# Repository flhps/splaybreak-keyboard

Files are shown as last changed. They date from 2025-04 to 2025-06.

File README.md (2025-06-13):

# SplayBreak

_A simple but versatile 36-key split ergonomic wireless keyboard._

---

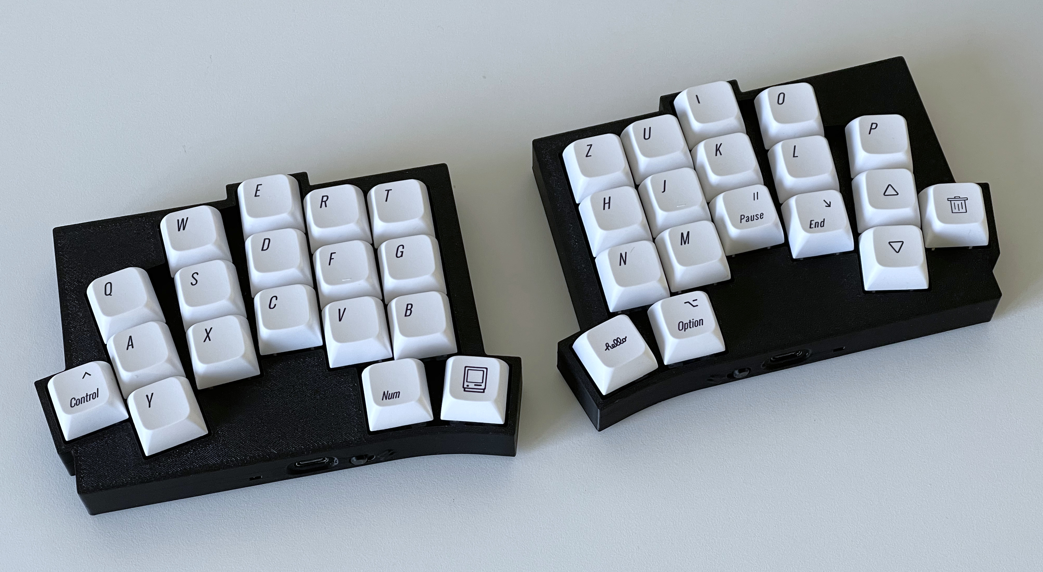
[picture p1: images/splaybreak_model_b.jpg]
Model B

_Model B with MX switches and XDA keycaps_
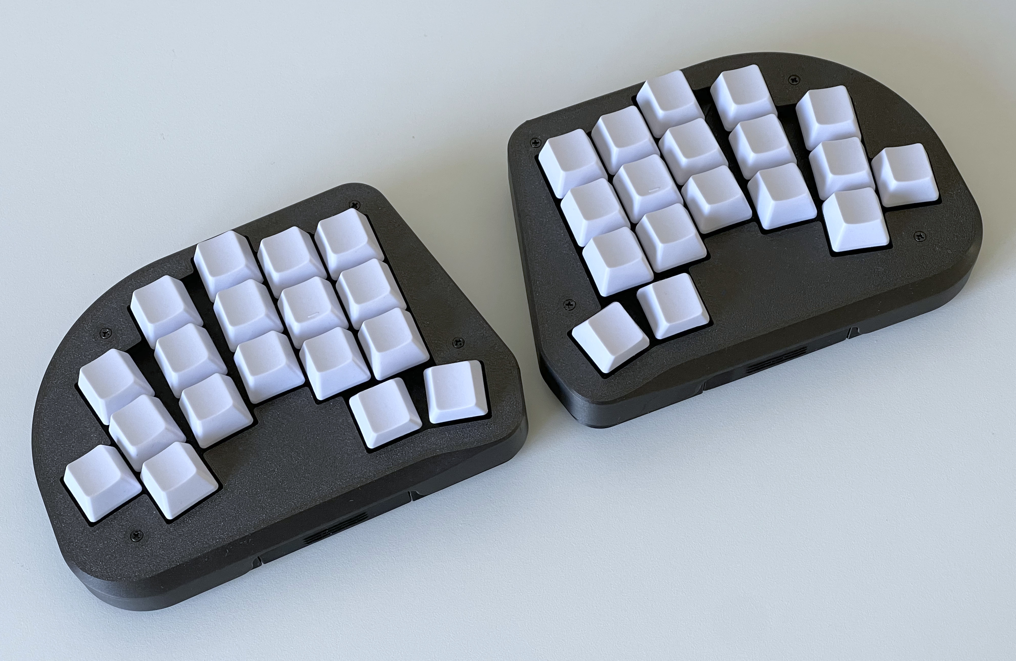
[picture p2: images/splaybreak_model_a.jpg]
Model A

_Model A with MX switches and OEM keycaps_

This is a split keyboard, that is heavily inspired by my recent personal dive into the world of open mechanical split keyboards. At the time of writing, I have used these two models on an almost daily basis for over 6 months.

## Features

There are two models that use the same PCB and mostly the same build parts:

| Model | Hot Swap MX | Hot Swap Choc V1 | Gasket Mount | Battery | Magnetic Access Hatch | Nice Buttons and Port |
| --- | --- | --- | --- | --- | --- | --- |
| [A](/build-guide-a.md) | ✅ | ⚠ | ✅ | 2000mAh | ✅ | |
| [B](/build-guide-b.md) | ✅ | ⚠ | | 500mAh  | | ✅ |

More information can be found in the individual build guides:

- [SplayBreak Model A](/build-guide-a.md)
- [SplayBreak Model B](/build-guide-b.md)

> [!WARNING]
> While the PCB accepts hot swap sockets for Choc V1 switches, the case dimensions are not tested with them.

## Design Rationale

A big focus was to keep this keyboard somewhat simple and cheap. That is why it uses the popular Pro Micro controllers and that limits the number of keys per side to 18 because we want to avoid having to solder diodes. The keyboards are wireless with massive batteries for easier daily use at home and on the go. Since the whole keyboard layout is in the firmware, these can also be used with devices such as phones or tablets. While screens can be cool, this design has none because they cost money and reduce battery life.

For flexibility (and cost reduction), the PCB is reversible. It means you need to order less and any PCB you have left can replace one that you accidentally destroyed. Also, the PCB has support for MX switches and Choc v1 switches. That would enable the use of this PCB for a super thin travel option.

There are only two thumb keys, because they would increase the design's footprint by a lot if they were to be positioned comfortably. The current inner thumb key is the resting position, meaning a third one would have to be even more toward the inside. However, I wanted to create a somewhat compact key arrangement and case.
Instead, the extra thumb key is moved to the pinky. This emulates the extra outer keys like tab or enter on a conventional keyboard an is intended to make it easier for people who frequently switch between conventional and split keyboards. It also makes switching from a conventional keyboard to this one easier.

This project features two different keyboard models, which only differ in assembly instructions and the provided case files, which are FDM-printable. I was never a big fan of the very gritty designs featuring lots of open electronics, so I designed some fully enclosed cases.

For repairability, model A has everything socketed, making error search and replacements easier. It is also built to improve sound through a gasket mount. Model B foregoes some of that and becomes more compact and arguably more stylish. There, the controller is soldered directly to the PCB.

## Firmware and Layout

Both models can use the same firmware. I have prepared a template that already contain a usable layout:

[zmk-config-splaybreak-template](https://github.com/flhps/zmk-config-splaybreak-template)

## Open Ideas and TODOs

- clean up the PCB and make it more aesthetic (transparent case?)
- create another model as a thin travel option with choc v1
- more in-depth build guides

## Development

Build ergogen in the `ergogen` directory:

```sh
ergogen --clean .
```

## Attributions

Big inspirations were:

- [TOTEM](https://github.com/GEIGEIGEIST/TOTEM)
- [Ferris Sweep](https://github.com/davidphilipbarr/Sweep)

The design uses ergogen footprints from [@ceoloide's ergogen PCB footprints](https://github.com/ceoloide/ergogen-footprints).
The reversible hotswap footprint for both MX and Choc is extracted from the [Lily58 Pro's](https://github.com/kata0510/Lily58) kicad file.

The [ergogen guide](https://flatfootfox.com/ergogen-introduction/) from FlatFootFox was very helpful.

And of course, this project would probably not exist without the excellent tool that is [ergogen](https://github.com/ergogen/ergogen).

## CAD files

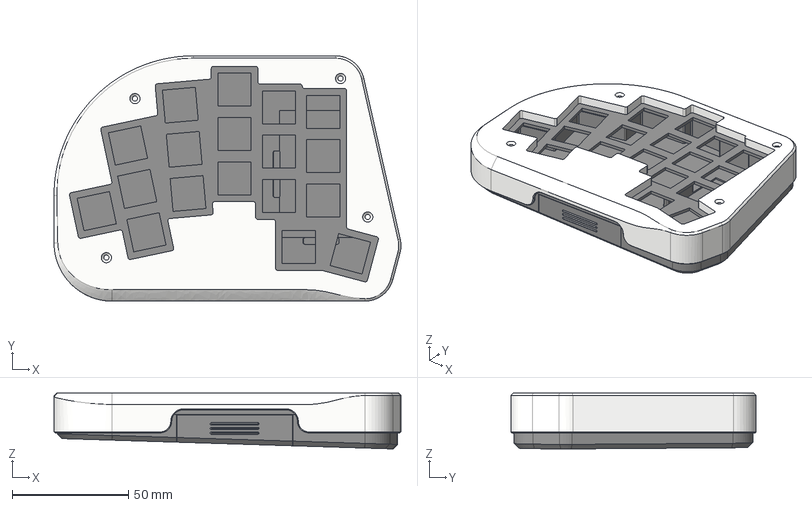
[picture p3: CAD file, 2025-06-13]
cases/SplayBreak Case Model A.step
149.1 x 105.4 x 24.0 mm

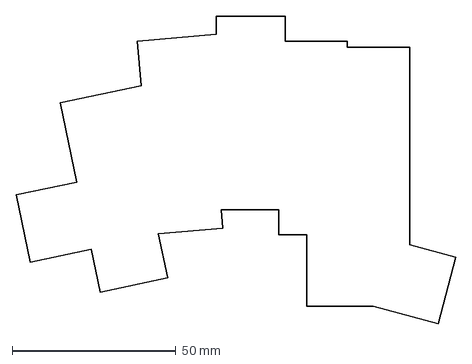
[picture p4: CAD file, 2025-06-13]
ergogen/output/outlines/combined_raw.dxf
134.3 x 94.0 mm

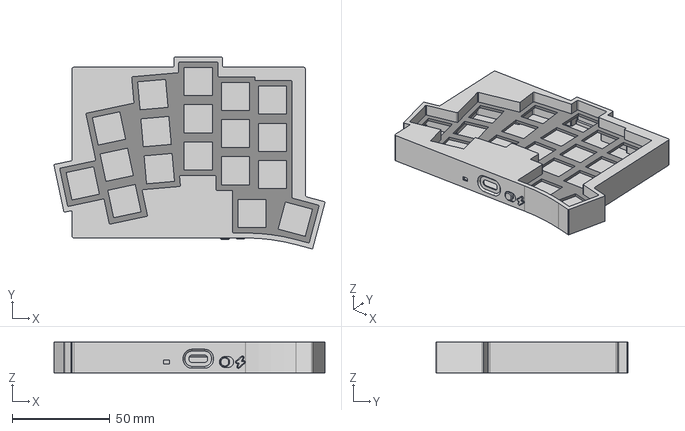
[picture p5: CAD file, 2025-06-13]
cases/SplayBreak Case Model B.step
139.0 x 98.3 x 15.7 mm

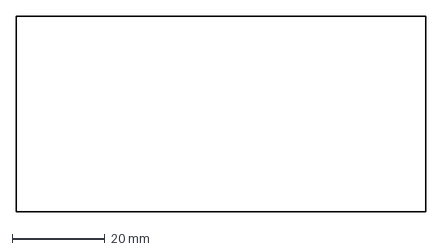
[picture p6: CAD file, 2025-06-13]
ergogen/output/outlines/io_rect.dxf
88.4 x 42.1 mm

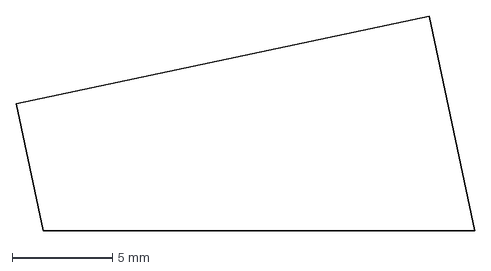
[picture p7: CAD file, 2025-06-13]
ergogen/output/outlines/io_patch.dxf
22.9 x 10.7 mm

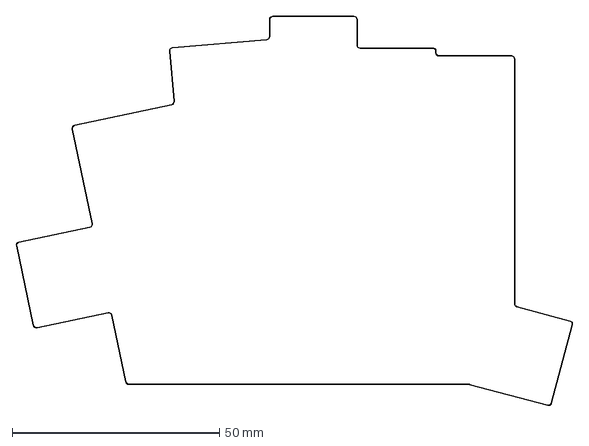
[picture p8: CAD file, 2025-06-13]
ergogen/output/outlines/board.dxf
134.2 x 93.8 mm

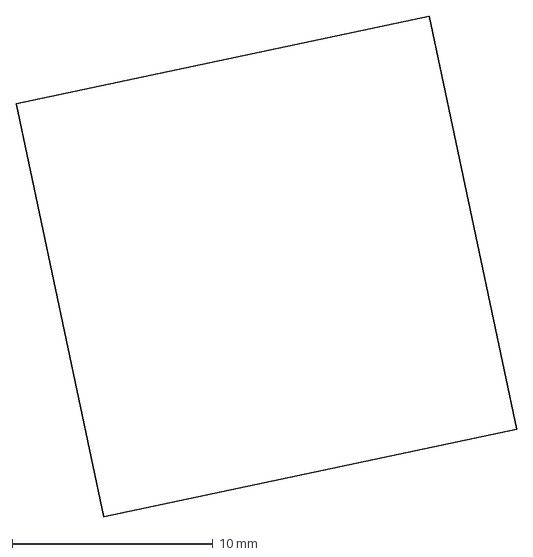
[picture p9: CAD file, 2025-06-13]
ergogen/output/outlines/io_fill.dxf
25.0 x 25.0 mm

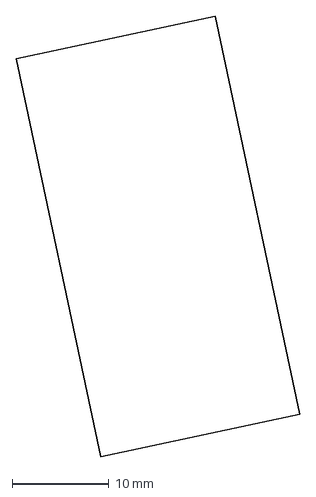
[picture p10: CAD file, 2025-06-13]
ergogen/output/outlines/pinky_right.dxf
29.3 x 45.6 mm

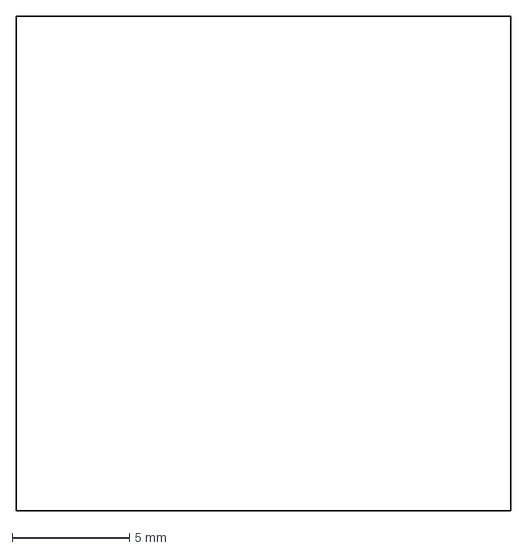
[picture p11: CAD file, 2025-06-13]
ergogen/output/outlines/thumb_up.dxf
21.0 x 21.0 mm

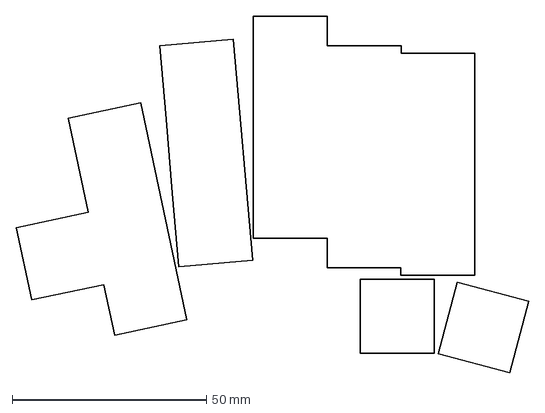
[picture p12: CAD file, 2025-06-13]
ergogen/output/outlines/keys.dxf
131.9 x 91.7 mm

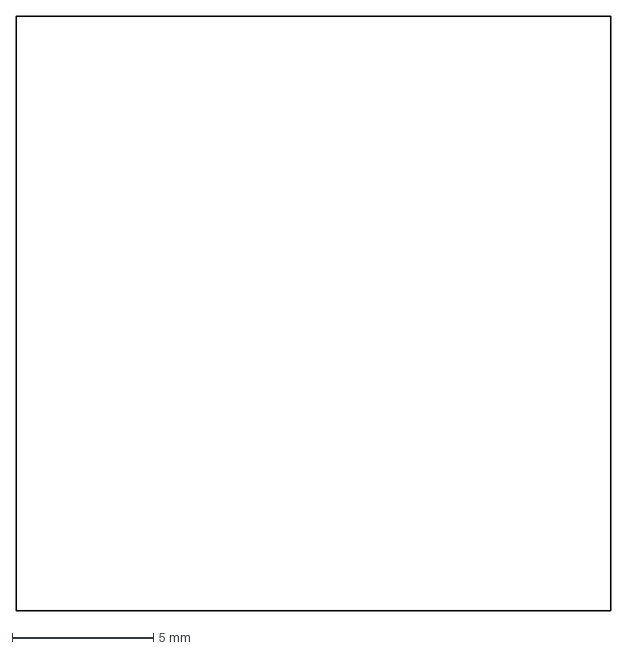
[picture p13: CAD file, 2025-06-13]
ergogen/output/outlines/inner_down.dxf
21.1 x 21.1 mm

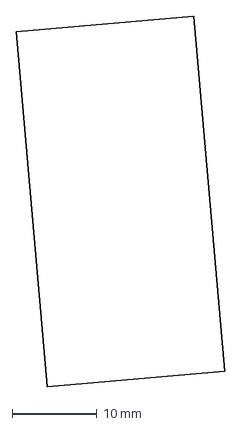
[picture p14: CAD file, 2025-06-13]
ergogen/output/outlines/ring_right.dxf
24.6 x 43.8 mm

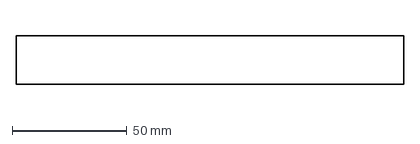
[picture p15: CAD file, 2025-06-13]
ergogen/output/outlines/io_fill2.dxf
168.4 x 21.0 mm

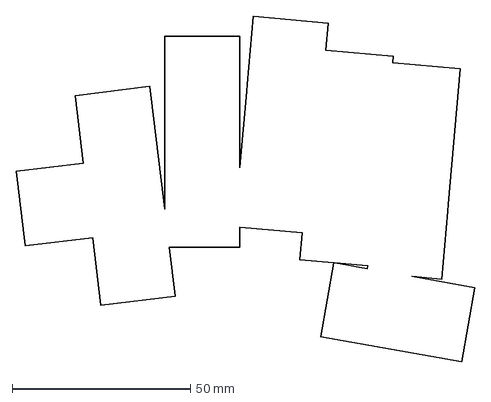
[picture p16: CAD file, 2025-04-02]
ergogen/output/outlines/raw.dxf
128.5 x 96.7 mm

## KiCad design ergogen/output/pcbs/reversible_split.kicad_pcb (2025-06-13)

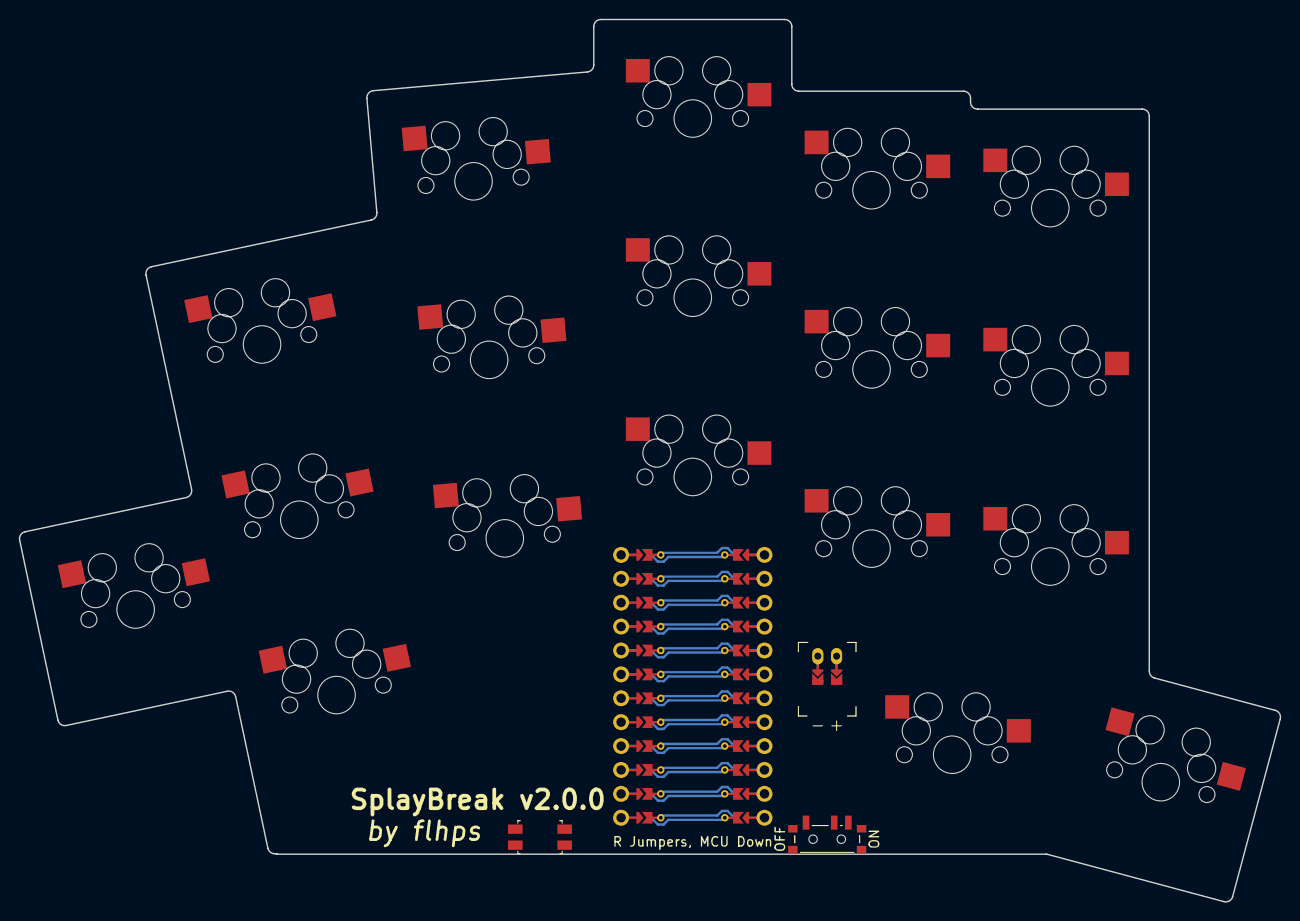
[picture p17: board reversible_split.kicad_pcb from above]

Board: 2 copper layers, 134.0 x 93.8 mm, 22 parts (0 on the bottom side), 24 nets.

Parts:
JST1: battery_connector_jst_ph_2
MCU1: mcu_nice_nano
PWR1: power_switch_smd_side
RST1: reset_switch_smd_side
S1, S2, S3, S4, S5, S6, S7, S8, S9, S10, S11, S12, S13, S14, S15, S16, S17, S18: MX

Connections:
GND: JST1.2, MCU1.103, MCU1.104, MCU1.123, RST1.1, RST1.3, S1.1, S2.1, S3.1, S4.1, S5.1, S6.1, S7.1, S8.1, S9.1, S10.1, S11.1, S12.1, S13.1, S14.1, S15.1, S16.1, S17.1, S18.1
JST1_1: JST1.11, JST1.21, JST1.31
JST1_2: JST1.12, JST1.22, JST1.32
RAW: MCU1.124, PWR1.2
RST: MCU1.122, RST1.2, RST1.4
matrix_index_bottom: MCU1.107, S11.2
matrix_index_home: MCU1.108, S12.2
matrix_index_top: MCU1.109, S13.2
matrix_inner_bottom: MCU1.110, S14.2
matrix_inner_home: MCU1.111, S15.2
matrix_inner_top: MCU1.112, S16.2
matrix_middle_bottom: MCU1.102, S8.2
matrix_middle_home: MCU1.105, S9.2
matrix_middle_top: MCU1.106, S10.2
matrix_outer_home: MCU1.115, S1.2
matrix_pinky_bottom: MCU1.116, S2.2
matrix_pinky_home: MCU1.117, S3.2
matrix_pinky_top: MCU1.118, S4.2
matrix_ring_bottom: MCU1.119, S5.2
matrix_ring_home: MCU1.120, S6.2
matrix_ring_top: MCU1.101, S7.2
pos: JST1.1, PWR1.1, PWR1.3
thumb_reachy: MCU1.113, S18.2
thumb_tucky: MCU1.114, S17.2

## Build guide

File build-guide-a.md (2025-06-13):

# Build Guide: SplayBreak Model A

Model A

This version is my original design with a massive PlayStation controller battery and a gasket mount. It also has enough space for foam or other sound-improving material in the bottom.

My personal build uses Gateron Oil King switches and Cherry profile key caps to create a satisfying and comfortable every-day setup.

## PCBs

You can order your PCB at services like JLCPCB or PCBWay. Download the gerbers ZIP archive from the [pcb](./pcb/) directory and upload them to the service.

Important Parameters:

- 1.6mm thickness
- 2 layers

Remember that 2 PCBs make 1 keyboard.

## Parts

These are the parts required for one Keyboard consisting of two halves. As a reference, I included rough pricing as of 2025 (worst-case pricing for minimum purchasable quantity). If you already have supplies, this may be much cheaper:

- 2x PCB (ca. 18€)
- 1x 3D printed model A case parts for left and right sides (ca. 2€ in material)
- 2x Pro Micro compatible controller with Bluetooth (ca. 12€)
- 4x 2.54mm pitch header row female (ca. 2€)
- 48x pins harvested from 4 or 5 pin RGB(W) headers by removing the plastic (ca. 2€)
- 2x 3.7v 2000mAh Sony PS4 controller battery pack with 2 pin JST PH 2.0mm plug (ca. 13€)
- 36x Kailh MX Hot Swap sockets (ca. 6€)
- 36x MX switches of preferred type (ca. 25€)
- 36x MX compatible keycaps (ca. 25€)
- 2x MSK-12C02 SMD toggle switch (ca. 2€)
- 2x EVQPUC02K SMD tactile switch (ca. 2€)
- 2x 2 pin JST PH 2.0mm housing (ca. 1€)
- various M2 standoffs to adapt to needed length depending on gasket (ca. 4x 22mm and 4x 18mm) (ca. 8€)
- 16x M2x6 countersunk screws (ca. 2€)
- 1x sheet of 3 mm poron foam (ca. 5€)
- 4x 6x3mm magnet (ca. 6€)
- 8x rubber feet (ca. 2€)

Total cost for building one keyboard is around 133€ and gets cheaper per unit if you build multiple.

For more information on the slightly unconventional controller socketing, consult this excellent [guide](https://github.com/joric/nrfmicro/wiki/Sockets#machine-pin-socket).

Optional:

- poron switch stickers for sound dampening
- painter's tape for tape modding
- some more foam or eraser putty for the bottom of the case

And of course you need solder supplies.

## Assembly

Take two PCBs mark opposing sides as the top side. Then, for each PCB:

1. Solder hot swap sockets on the bottom side.
2. Solder the toggle switch as power switch and the tactile switch as reset button. Put both on the bottom side.
3. Break the header rows to a length of 12 and solder the header rows for the controllers to the bottom side of the PCB. Put a piece of painter's tape over the sockets to prevent solder from dripping down. Lay the controller on the sockets such that the processor chip faces the PCB and put in all the pins, forcing them through the painer's tape. Then, solder the pins to the controller. Cut off the remaining length of the pins to keep the controller as flat as possible. Remove the painter's tape. Bridge the solder pads on the top side.
4. Solder the JST housing as a connection point for the battery on the bottom side. Bridge the solder pads on the top side.
5. Glue the magnets into the round recesses in the access hatches and frames.
6. Put standoffs into the 4 channels of the case's bottom part and screw them in from the bottom. Put the middle case part in the bottom one.
7. Cut out a strip of poron foam for each recess in the case's bottom and top part and place them in there.
8. Put the case's key plate on the PCB and insert switches to connect them.
9. Plug the battery connector in and lay the battery in its compartment in the case's bottom. Then lay the key pate (and PCB) with its tabs on the poron foam.
10. Carefully place the case's top part on the bottom part without the poron strips falling out. Secure the case by screwing in the top screws.
11. Put some rubber feet under the bottom plate.

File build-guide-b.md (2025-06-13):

# Build Guide: SplayBreak Model B

Model B

This version is a more stylish variant intended for travel. It is a little lighter and more compact, but has a smaller battery. Still, it should last weeks on one charge.

My personal build uses silent TTC Frozen V2 switches and XDA profile keycaps to create a compact office and travel keyboard.

## PCBs

You can order your PCB at services like JLCPCB or PCBWay. Download the gerbers ZIP archive from the [pcb](./pcb/) directory and upload them to the service.

Important Parameters:

- 1.6mm thickness
- 2 layers

Remember that 2 PCBs make 1 keyboard.

## Parts

These are the parts required for one Keyboard consisting of two halves. As a reference, I included rough pricing as of 2025 (worst-case pricing for minimum purchasable quantity). If you already have supplies, this may be much cheaper:

- 2x PCB (ca. 18€)
- 1x 3D printed model B case parts for left and right sides (ca. 1€ in material)
- 2x Pro Micro compatible controller with Bluetooth (ca. 12€)
- 2x 3.7V 500 mAh LiPo battery model 402030 with 2 pin JST PH 2.0mm plug (ca. 4€)
- 36x Kailh MX Hot Swap sockets (ca. 6€)
- 36x MX switches of preferred type (ca. 25€)
- 36x MX compatible keycaps (ca. 25€)
- 2x MSK-12C02 SMD toggle switch (ca. 2€)
- 2x EVQPUC02K SMD tactile switch (ca. 2€)
- 2x 2 pin JST PH 2.0mm housing (ca. 1€)
- 8x M2x6 countersunk screws (ca. 2€)
- 8x rubber feet (ca. 2€)

Total cost for building one keyboard is around 100€ and gets cheaper per unit if you build multiple.

Optional:

- poron switch stickers for sound dampening
- painter's tape for tape modding

And of course you need solder supplies.

## Assembly

Take two PCBs mark opposing sides as the top side. Then, for each PCB:

1. Solder hot swap sockets on the bottom side.
2. Solder the toggle switch as power switch and the tactile switch as reset button. Put both on the top side.
3. Solder the controller on the top side with the USB port toward the PCB edge. Sandwich the included header pin rows between the controller and the PCB with the controller being upside down. The header pin row creates the necessary clearance for the USB port. After soldering, cut off the remaining pin length on top and bottom (max 0.5mm left standing). Bridge the solder pads on the bottom side.
4. Solder the JST housing as a connection point for the battery on the top side. Bridge the solder pads on the bottom side.
5. Put on the case's key plate and put in switches to connect it to the PCB.
6. Put the battery in the case top's compartment. Optionally secure it with some non-conductive tape.
7. Plug the battery connector in and insert the case's power switch in the top case cutout. Put the PCB assembly into the case top without crushing the Battery cable and without shearing off the power switch. This a bit tricky, so take your time.
8. Close the case by inserting the case's bottom plate and screw the 4 screws directly into the plastic.
9. Put some rubber feet under the bottom plate.

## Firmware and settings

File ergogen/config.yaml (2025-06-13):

# `U` is a predefined unit of measure that means 19.05mm, which is MX spacing
meta:
  engine: 4.1.0
units:
  pu: U + 2
points:
  zones:
    matrix:
      columns:
        outer:
          rows.bottom.skip: true
          rows.top.skip: true
        pinky.key.stagger: 0.3U
        ring.key:
          stagger: 0.66U
          splay: -7
          spread: 1.1U
        middle.key:
          stagger: 0.25U
          splay: -5
          spread: 1.075U
        index.key.stagger: -0.4U
        inner.key.stagger: -0.1U
      rows:
        bottom.padding: U
        home.padding: U
        top.padding: U
      rotate: 12
      anchor:
        # Shift the PCB slightly to the right and down, otherwise it's weirdly positioned outside of the main sheet in KiCad
        shift: [100, -150]
    thumb:
      anchor:
        ref: matrix_index_bottom
        shift: [0.45U, -1.15U]
      columns:
        tucky:
          key.name: thumb_tucky
          key.splay: 0
        reachy:
          key.spread: 1U
          key.splay: -15
          key.origin: [-0.5U, -0.7U]
          key.name: thumb_reachy
outlines:
  keys:
    - what: rectangle
      where: true
      size: [1U, 1U]
  raw:
    - what: rectangle
      where: true
      size: [1pu, 1pu]
  pinky_right:
    - what: rectangle
      where:
        - ref: matrix_pinky_top
          shift: [1.0U, -0.5pu]
      size: [1pu, 2pu]
  ring_right:
    - what: rectangle
      where:
        - ref: matrix_ring_top
          shift: [1.0U, -0.5pu]
      size: [1pu, 2pu]
  thumb_up:
    - what: rectangle
      where:
        - ref: thumb_tucky
          shift: [0U, 1U]
      size: [1pu, 1pu]
  inner_down:
    - what: rectangle
      where:
        - ref: matrix_inner_bottom
          shift: [0U, -0.9U]
      size: [1pu, 1pu]
  combined_raw:
    - name: raw
    - operation: add
      name: pinky_right
    - operation: add
      name: ring_right
    - operation: add
      name: thumb_up
    - operation: add
      name: inner_down
  io_rect:
    - what: rectangle
      where:
        - ref: matrix_middle_bottom
          shift: [0pu, -1U]
          rotate: 0
      size: [4.2pu, 2pu]
  io_fill:
    - what: rectangle
      where:
        - ref: matrix_pinky_bottom
          shift: [0pu, -1U]
          rotate: 0
      size: [1pu, 1pu]
  io_fill2:
    - what: rectangle
      where:
        - ref: thumb_tucky
          shift: [-4pu, 0U]
          rotate: 0
      size: [8pu, 1pu]
  io_patch:
    - name: io_fill
    - operation: intersect
      name: io_fill2
  board:
    - name: combined_raw
    - operation: add
      name: io_rect
    - operation: add
      name: io_patch
      fillet: 0.75
pcbs:
  reversible_split:
    template: kicad8
    outlines:
      main:
        outline: board
    footprints:
      keys:
        what: mx
        where: true
        params:
          from: GND
          to: "{{name}}"
          reverse: true
          keycaps: true
          hotswap: true
      mcu:
        what: mcu_nice_nano
        where:
          - ref: matrix_middle_bottom
            shift: [0U, -1.235U]
            rotate: 180
        params:
          reversible: true
          reverse_mount: true
          show_silk_labels: false
          show_via_labels: false
          # right side pins
          P21: matrix_ring_home
          P20: matrix_ring_bottom
          P19: matrix_pinky_top
          P18: matrix_pinky_home
          P15: matrix_pinky_bottom
          P14: matrix_outer_home
          P16: thumb_tucky
          P10: thumb_reachy
          # left side pins
          P1: matrix_ring_top
          P0: matrix_middle_bottom
          P2: matrix_middle_home
          P3: matrix_middle_top
          P4: matrix_index_bottom
          P5: matrix_index_home
          P6: matrix_index_top
          P7: matrix_inner_bottom
          P8: matrix_inner_home
          P9: matrix_inner_top
      battery_connector:
        what: battery_connector_jst_ph_2
        where:
          ref:
            - matrix_middle_bottom
          shift: [0.75U, -1U]
          rotate: 0
        params:
          reversible: true
          BAT_N: GND
          BAT_P: pos
      on_off_switch:
        what: power_switch_smd_side
        where:
          ref:
            - matrix_middle_bottom
          shift: [0.75U, -2.02U]
          rotate: -90
        params:
          reversible: true
          from: pos
          to: RAW
      horizontal_reset:
        what: reset_switch_smd_side
        where:
          ref:
            - thumb_tucky
          shift: [-2.3U, -0.46U]
          rotate: -180
        params:
          reversible: true
          from: GND
          to: RST
      version_text:
        what: utility_text
        where:
          - ref: matrix_middle_bottom
            shift: [-1.2U, -1.8U]
        params:
          reversible: true
          height: 2
          width: 2
          thickness: 0.4
          text: "SplayBreak v2.0.0"
      author_text:
        what: utility_text
        where:
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

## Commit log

2024-08-31 Initial Design
    [board.dxf, control.dxf, keys.dxf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]
2025-04-02 Iteration One (#1)
    * Tighter outline
    * First complete layout
    * Rotated layout experiment
    * Updated SMD positions
    * First Complete PCB
    [board.dxf, control.dxf, keys.dxf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]
2025-04-02 New ergogen config finalized
    [board.dxf, combined_raw.dxf, control.dxf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]
2025-04-02 Replaced mx footprint with hybrid footprint
    [reversible_split.kicad_pcb]
2025-04-02 Manually flipped mc footprint
    The ergogen footprint for the mcu seems buggy.
    [reversible_split.kicad_pcb]
2025-04-02 Routed quick and dirty
    [reversible_split.kicad_pcb]
2025-04-02 Final production files
    [reversible_split-B_Cu.gbr, reversible_split-B_Mask.gbr, reversible_split-B_Paste.gbr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]
2025-04-02 Reverted name change
    [reversible_split-B_Cu.gbr, reversible_split-B_Mask.gbr, reversible_split-B_Paste.gbr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]
2025-06-13 Added case step files
    [SplayBreak Case Model A.step, SplayBreak Case Model B.step]
2025-06-13 Regenerated build files with updated text
    [reversible_split-B_Cu.gbr, reversible_split-B_Mask.gbr, reversible_split-B_Paste.gbr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]
